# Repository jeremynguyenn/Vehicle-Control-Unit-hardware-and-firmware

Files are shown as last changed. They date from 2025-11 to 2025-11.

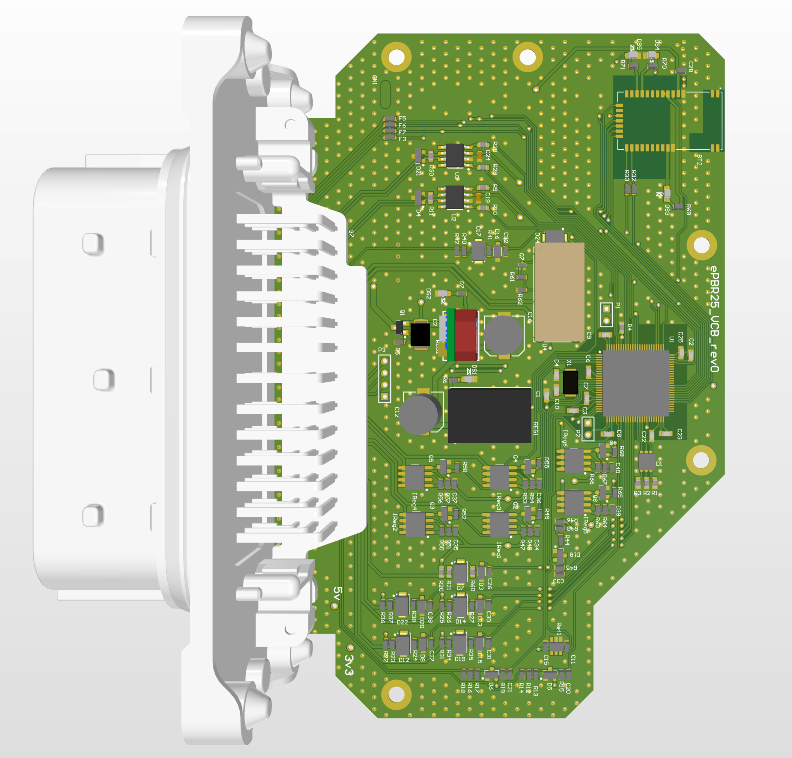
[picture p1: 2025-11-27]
picture/3d_layer_left.png

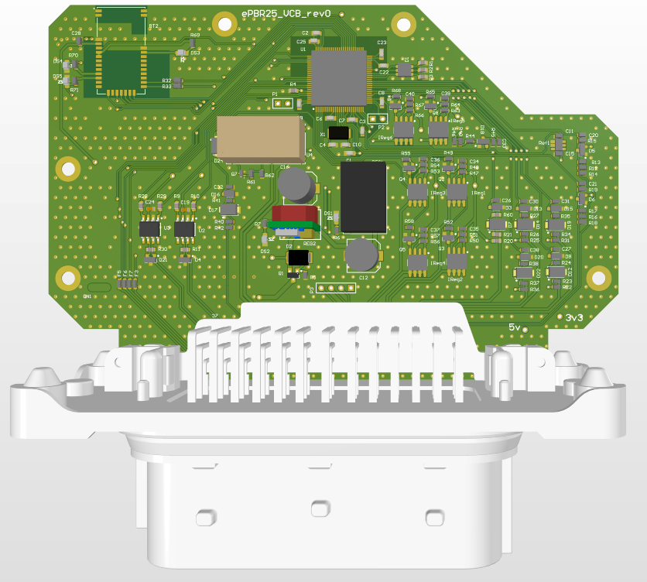
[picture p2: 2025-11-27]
picture/3d_layer.png

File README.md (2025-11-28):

## Picture for the VCU for Electric Vehicle
- 3d View:


- 2d view:


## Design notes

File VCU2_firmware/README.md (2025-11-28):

# Vehicle Control Unit (VCU)

## Introduction
This repository contains the code for the Vehicle Control Unit (VCU) of the Formula Electric SAE Student Team UMSAE Electric. 
The VCU is responsible for the control of the vehicle, including the motor controller, the steering system, and the brake system. 
The VCU is also responsible for the communication with the other ECUs in the vehicle, such as the Accumulator Control Unit (ACU) and the Sensor Control Unit (SCU).

## Building the code
The code is built using STM32CubeIDE.

### Prerequisites
- [STM32CubeIDE](https://www.st.com/en/development-tools/stm32cubeide.html) 
- [STM32CubeMX](https://www.st.com/en/development-tools/stm32cubemx.html)(optional)

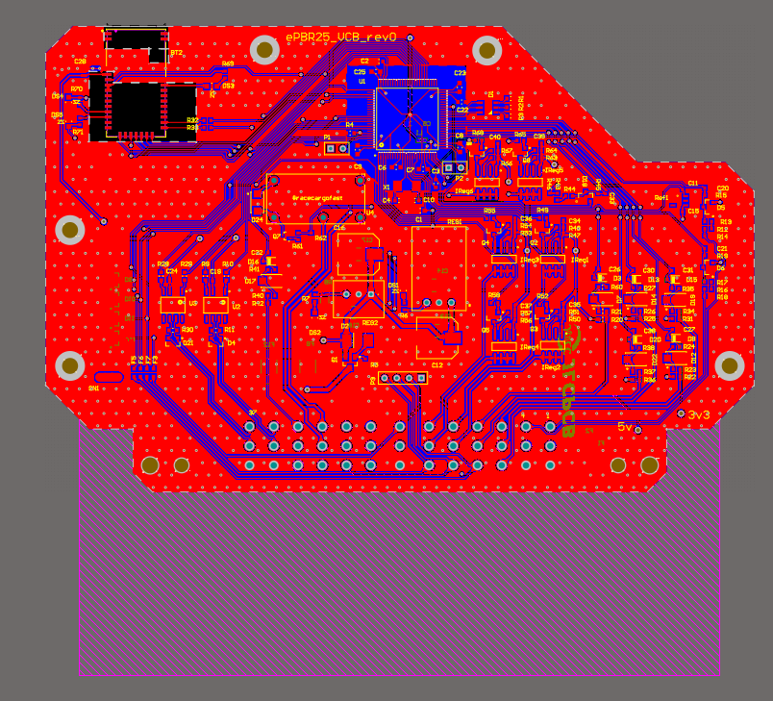
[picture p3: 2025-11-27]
picture/2d_layer.png

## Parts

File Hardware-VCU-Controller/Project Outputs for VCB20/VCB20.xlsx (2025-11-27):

Comment | Description | Designator | Footprint | LibRef | Quantity
WT12 |  | BT1 | WT12 | WT12 | 1
CAP 10nF 100V 0603(1608) | CAP 10nF 100V ±20% 0603 (1608 Metric) Thickness 1mm SMD | C1, C5, C6, C7, C8, C9, C23, C25 | CAPC0603(1608)100_M | CMP-1035-02326-1 | 8
CAP 2.2uF | CAP 2.2uF 10V ±10% 0603 (1608 Metric) Thickness 0.55mm SMD | C2 | CAPC0603(1608)55_N | CMP-1035-02757-1 | 1
CAP 100nF 25V 0603(1608) | CAP 100nF 25V ±20% 0603 (1608 Metric) Thickness 1mm SMD | C3 | CAPC0603(1608)100_N | CMP-1035-02589-1 | 1
CAP 24pF | CAP 24pF 16V ±2% 0603 (1608 Metric) Thickness 1mm SMD | C4, C10 | CAPC0603(1608)100_N | CMP-1035-00843-1 | 2
Cap | Capacitor | C11, C15, C20, C21, C26, C27, C28, C29, C30, C31, C32, C33, C34, C35, C36, C37, C38 | 1608[0603] | Cap | 17
UUD1H101MNL1GS | Aluminum Electrolytic Capacitor, UD Series, Low Impedance, 100 uF, 50 V, + / - 20%, -55 to 105 degC, Chip Type, 8 x 10 mm D x L, Pb-Free, Reel | C12, C16 | NIC-CAPA2-8X10_V | CMP-0687-00073-1 | 2
Cap | Capacitor | C13, C14, C17, C18 | C1210_M | Cap | 4
0.1uF | Chip Capacitor, 100 nF, +/- 10%, 50 V, -55 to 125 degC, 0603 (1608 Metric), RoHS, Tape and Reel | C19, C24 | CAPC1608X90X30NL10T20 | CMP-2000-06092-1 | 2
CAP 2.2uF 10V 0603(1608) | CAP 2.2uF 10V ±10% 0603 (1608 Metric) Thickness 0.55mm SMD | C22 | CAPC0603(1608)55_N | CMP-1035-02757-1 | 1
5-1418363-3 | Levyseal 90 degree 39 pin header | CN1 | 5-1418363-3 | 5-1418363-3 | 1
CLX6F-FKC-CNP1ST1E1BB7D3D3 | Red, Green, Blue (RGB) 622nm Red, 530nm Green, 470nm Blue LED Indication - Discrete 2.1V Red, 2.7V Green, 3V Blue 6-SMD, J-Lead | D1 | CLX6C-FKB | LED - CLX6F-FKC-CNP1ST1E1BB7D3D3 | 1
Zener Diode, 5.1V, 5W SMBJ5338B |  | D2 | DO-214AA (SMB) | Zener Diode, 5.1V, 5W SMBJ5338B | 1
MMSZ5226B-E3-08 | Small Signal Zener Diode, 3.3 V +/- 5%, -55 to 155 degC, 2-Pin SOD-123, RoHS, Tape and Reel | D3, D8, D13, D15, D16, D20 | VISH-SOD-123-2_V | CMP-0931-00026-1 | 6
NUP2105LT1 | Dual Line CAN Bus Protector, 3-Pin SOT-23, Tape and Reel | D4, D21 | ONSC-SOT-23-3-318-08_V | CMP-1063-00165-1 | 2
SZNUP1301ML3T1G | Low Capacitance Diode Array for ESD Protection in a Single Data Line, 3-Pin SOT-23, Pb-Free, Tape and Reel | D5, D6, D9, D10, D11, D18, D23 | ONSC-SOT-23-3-318-08_V | CMP-1063-00171-1 | 7
SS14-E3/5AT | Schottky Barrier Rectifier, 40 V Maximum DC Blocking Voltage, -65 to 125 degC, 2-Pin SMA Case, RoHS | D7, D12, D14, D17, D19, D22, D24 | VISH-DO-214AC-2_V | CMP-0549-00004-1 | 7
LTST-C170GKT | LED Uni-Color Green, 100 mW, 120 mA, -55 to 85 degC, 2-Pin SMD, RoHS, Tape and Reel | DS1, DS2 | LTST-C170GKT_V | CMP-1674-00002-5 | 2
PTC 80 mA | 0ZCM0008FF2G | F1, F2, F3, F5, F6, F7 | 0603 fuse | PTC fuse 80mA 0ZCM0008FF2G | 6
1812L075/24DR | Poly-Fuse(R) Resettable PTC, 24 V, 100 A, -40 to 85 degC, 2-Pin SMD, RoHS, Tape and Reel | F8, F11 | LFUS-1812L07524DR_V | CMP-2000-05510-1 | 2
1812L050/30PR | PTC Resettable Fuse, 0.8 W, 30 V, -40 to 85 degC, 2-Pin SMD, RoHS, Tape and Reel | F9, F10 | LFUS-1812L05030PR_V | CMP-2000-05508-1 | 2
NUD4001 |  | IReg1, IReg2, IReg3, IReg4 | SO8_M | LED Currnet Driver, 500mA, 30V max | 4
MH1608-601Y | Chip Bead, 600 Ohm, 1 A, -55 to 125 degC, 2-Pin SMD (0603), RoHS, Tape and Reel | L1 | BOUR-MH1608_V | CMP-2000-06698-1 | 1
Header 2 | Header, 2-Pin | P1, P2 | HDR1X2 | Header 2 | 2
Header 4 | Header, 4-Pin | P3 | HDR1X4 | Header 4 | 1
FDN340P | Single P-Channel, Logic Level, PowerTrench(R) MOSFET, 2 A, 20 V, -55 to 150 degC, 3-Pin SOT-23, RoHS, Tape and Reel | Q1 | FAIR-SSOT3L-3_V | CMP-2100-03638-1 | 1
MMBT2222ALT1 | General Purpose Transistor, NPN Silicon, 3-Pin SOT-23, Tape and Reel | Q2, Q3, Q4, Q5 | ONSC-SOT-23-3-318-08_V | CMP-1048-00593-1 | 4
IRF7413PBFCT | HEXFET (R) Power MOSFET, 30 V, -55 to 150 degC, 8-Pin SO, RoHS, Tube | Q6 | INTR-SO-8_V | CMP-2000-06466-1 | 1
NTA7002NT1G | Small Signal MOSFET, 30 V, 154 mA, Single, N-Channel, Gate ESD Protection, 3-Pin SC75, Pb-Free, Tape and Reel | Q7 | ONSC-SC-75-3-463-01_V | CMP-1058-00646-1 | 1
82R | 82R 0.1W 5% 0603 (1608 Metric) SMD | R1 | RESC0603(1608)_N | CMP-1012-00048-1 | 1
60R | 60R4 0.1W 1% 0603 (1608 Metric) SMD | R2 | RESC0603(1608)_N | CMP-1012-00372-1 | 1
33R | 33R 0.1W 5% 0603 (1608 Metric) SMD | R3 | RESC0603(1608)_N | CMP-1012-00038-1 | 1
10K | 10K 0.1W 5% 0603 (1608 Metric) SMD | R4 | RESC0603(1608)_N | CMP-1012-00098-1 | 1
Res1 | Resistor | R5, R6, R7, R12, R13, R14, R15, R16, R17, R18, R19, R22, R23, R24, R25, R26, R27, R31, R32, R33, R34, R35, R36, R37, R38, R40, R41, R42, R43, R44, R45, R46, R47, R48, R49, R50, R51, R52, R53, R54, R55, R56, R57, R58, R61, R62 | 1608[0603] | Res1 | 46
100R | 100R 0.25W 5% 1206 (3216 Metric) SMD | R8 | RESC1206(3216)_M | CMP-1014-00050-1 | 1
22R | 22R 0.1W 5% 0603 (1608 Metric) SMD | R9, R10, R28, R29 | RESC0603(1608)_N | CMP-1012-00034-1 | 4
120R | 120R 0.1W 5% 0603 (1608 Metric) SMD | R11, R30 | RESC0603(1608)_N | CMP-1012-00052-1 | 2
100K 5% 0603(1608) | 100K 0.1W 5% 0603 (1608 Metric) SMD | R20 | RESC0603(1608)_N | CMP-1012-00122-1 | 1
51K 5% 0603(1608) | 51K 0.1W 5% 0603 (1608 Metric) SMD | R21, R60 | RESC0603(1608)_N | CMP-1012-00115-1 | 2
100R 1% 0603(1608) | 100R 0.1W 1% 0603 (1608 Metric) SMD | R39 | RESC0603(1608)_N | CMP-1012-00397-1 | 1
10K 1% 0603(1608) | 10K 0.1W 1% 0603 (1608 Metric) SMD | R59 | RESC0603(1608)_N | CMP-1012-00623-1 | 1
LT6654AHS6-3.3 |  | Ref1 | TSOT-23 S6 | LT6654AHS6-3.3 | 1
OKI-78SR-5 |  | REG1 | Reg - TH, 3 pin, 100 mil Pitch, HTL | OKI-78SR-5 | 1
OKI-78SR-3.3 | 3.3V DCDC | REG2 | Reg - TH, 3 pin, 100 mil Pitch, VTL | OKI-78SR-5 | 1
STM32F446VET7 | ARM Cortex-M4 32-bit MCU+FPU, 512 KB Flash, 128 KB Internal RAM, 81 I/Os, 100-Pin LQFP, -40 to 105 degC, Tray | U1 | STM-LQFP100_L | CMP-0243-00221-1 | 1
SN65HVD232DR | 3.3 V Can Transceiver, 17 mA, -40 to 85 degC, 8-pin SOIC (D), Green (RoHS & no Sb/Br) | U2, U3 | D0008A_M | CMP-0315-00075-2 | 2
PE014005 |  | U4 | PE014005 | PE014005 | 1
7A-8.000MAAJ-T |  | X1 | 2-SMD, No Lead | 8MHz crystal, 7A-8.000MAAJ-T | 1

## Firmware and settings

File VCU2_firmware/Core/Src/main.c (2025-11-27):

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
/* Includes ------------------------------------------------------------------*/
#include "main.h"
#include "cmsis_os.h"
#include "adc.h"
#include "can.h"
#include "dma.h"
#include "tim.h"
#include "usart.h"
#include "gpio.h"

/* USER CODE BEGIN Includes */
#include "dashboard_leds.h"
#include "logger.h"
#include "startup_condition.h"
#include "bt_protocol.h"
/* USER CODE END Includes */


void SystemClock_Config(void);
void MX_FREERTOS_Init(void);
/**
  * @brief  The application entry point.
  * @retval int
  */
int main(void)
{

  /* MCU Configuration--------------------------------------------------------*/

  /* Reset of all peripherals, Initializes the Flash interface and the Systick. */
  HAL_Init();

  /* Configure the system clock */
  SystemClock_Config();

  /* Initialize all configured peripherals */
  MX_GPIO_Init();
  MX_DMA_Init();
  MX_CAN1_Init();
  MX_USART2_Init();
  MX_TIM12_Init();
  MX_ADC1_Init();
  /* USER CODE BEGIN 2 */
    dash_set_all_leds();

    if(!logInitialize()){
        //TODO VCU#32 ERROR log initialization failed
        vcu_debug_led(REDLED, true);
    }

    btInitialize();
    checkStartupCondition();

    dash_clear_all_leds();

    vcu_debug_led(GREENLED, true);
    logMessage("INIT: Starting Scheduler\r\n", true);

  /* USER CODE END 2 */

  /* Init scheduler */
  osKernelInitialize();

  /* Call init function for freertos objects (in cmsis_os2.c) */
  MX_FREERTOS_Init();

  /* Start scheduler */
  osKernelStart();

  /* We should never get here as control is now taken by the scheduler */

  /* Infinite loop */
  /* USER CODE BEGIN WHILE */
  while (1)
  {
    /* USER CODE END WHILE */

    /* USER CODE BEGIN 3 */
  }
  /* USER CODE END 3 */
}

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
/**
  * @brief  Period elapsed callback in non blocking mode
  * @note   This function is called  when TIM10 interrupt took place, inside
  * HAL_TIM_IRQHandler(). It makes a direct call to HAL_IncTick() to increment
  * a global variable "uwTick" used as application time base.
  * @param  htim : TIM handle
  * @retval None
  */
void HAL_TIM_PeriodElapsedCallback(TIM_HandleTypeDef *htim)
{
  if (htim->Instance == TIM10) {
    HAL_IncTick();
  }
}

/**
  * @brief  This function is executed in case of error occurrence.
  * @retval None
  */
void Error_Handler(void)
{
  /* USER CODE BEGIN Error_Handler_Debug */
  /* User can add his own implementation to report the HAL error return state */
  //TODO LEDs
  //TODO Error Handling
    //__disable_irq();
    logMessage("ERROR\r\n", true);
    //__enable_irq();
  /* USER CODE END Error_Handler_Debug */
}

#ifdef  USE_FULL_ASSERT
/**
  * @brief  Reports the name of the source file and the source line number
  *         where the assert_param error has occurred.
  * @param  file: pointer to the source file name
  * @param  line: assert_param error line source number
  * @retval None
  */
void assert_failed(uint8_t *file, uint32_t line)
{
  /* USER CODE BEGIN 6 */
  /* User can add his own implementation to report the file name and line number,
     ex: printf("Wrong parameters value: file %s on line %d\r\n", file, line) */
  /* USER CODE END 6 */
}
#endif /* USE_FULL_ASSERT */

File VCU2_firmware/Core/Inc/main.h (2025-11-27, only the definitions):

#define CAN_TX_TASK_ENABLED 1
#define MC_HRTBEAT_TASK_ENABLED 1
#define IWDG_RELOAD_PERIOD 4094
#define BT_DUMP_TASK_ENABLED 0
#define APPS_PROC_TASK_ENABLED 1
#define ACU_HRTBEAT_TASK_ENABLED 1
#define VCU_STATE_TASK_ENABLED 1
#define DASH_LED_TASK_ENABLED 1
#define MC_CAN_COMMS_TASK_ENABLED 1
#define DEFAULT_TASK_ENABLED 0
#define CAN_RX_TASK_ENABLED 1
#define WATCH_DOG_TASK_ENABLED 1
#define ACU_CAN_COMMS_TASK_ENABLED 1
#define IWDG_EVENT_ALL_ALLOWED_BITS 0xFFFFFF
#define RTD_LED2_BLUE_Pin GPIO_PIN_2
#define RTD_LED2_BLUE_GPIO_Port GPIOE
#define TSA_LED2_GREEN_Pin GPIO_PIN_3
#define TSA_LED2_GREEN_GPIO_Port GPIOE
#define RTD_LED1_GREEN_Pin GPIO_PIN_4
#define RTD_LED1_GREEN_GPIO_Port GPIOE
#define TSA_LED1_BLUE_Pin GPIO_PIN_5
#define TSA_LED1_BLUE_GPIO_Port GPIOE
#define APPS1_Pin GPIO_PIN_0
#define APPS1_GPIO_Port GPIOC
#define BPS_Pin GPIO_PIN_2
#define BPS_GPIO_Port GPIOC
#define LC_LED_Pin GPIO_PIN_0
#define LC_LED_GPIO_Port GPIOA
#define TC_LED_Pin GPIO_PIN_1
#define TC_LED_GPIO_Port GPIOA
#define APPS2_Pin GPIO_PIN_5
#define APPS2_GPIO_Port GPIOA
#define VBATT_Pin GPIO_PIN_7
#define VBATT_GPIO_Port GPIOA
#define TRACTION_BTN_Pin GPIO_PIN_5
#define TRACTION_BTN_GPIO_Port GPIOC
#define TSA_BTN_Pin GPIO_PIN_0
#define TSA_BTN_GPIO_Port GPIOB
#define RTD_BTN_Pin GPIO_PIN_1
#define RTD_BTN_GPIO_Port GPIOB
#define LAUNCH_BTN_Pin GPIO_PIN_2
#define LAUNCH_BTN_GPIO_Port GPIOB
#define VCU_LED_BLUE_Pin GPIO_PIN_8
#define VCU_LED_BLUE_GPIO_Port GPIOE
#define VCU_LED_GREEN_Pin GPIO_PIN_9
#define VCU_LED_GREEN_GPIO_Port GPIOE
#define VCU_LED_RED_Pin GPIO_PIN_10
#define VCU_LED_RED_GPIO_Port GPIOE
#define SHUTDOWN_CTL_Pin GPIO_PIN_12
#define SHUTDOWN_CTL_GPIO_Port GPIOE
#define BT_TX_Pin GPIO_PIN_8
#define BT_TX_GPIO_Port GPIOD
#define BT_RX_Pin GPIO_PIN_9
#define BT_RX_GPIO_Port GPIOD
#define BT_RESET_Pin GPIO_PIN_10
#define BT_RESET_GPIO_Port GPIOD
#define BT_NCTS_Pin GPIO_PIN_11
#define BT_NCTS_GPIO_Port GPIOD
#define BT_NRTS_Pin GPIO_PIN_12
#define BT_NRTS_GPIO_Port GPIOD
#define BT_SW_BTN_Pin GPIO_PIN_13
#define BT_SW_BTN_GPIO_Port GPIOD
#define BT_P2_4_Pin GPIO_PIN_14
#define BT_P2_4_GPIO_Port GPIOD
#define BT_P2_0_Pin GPIO_PIN_15
#define BT_P2_0_GPIO_Port GPIOD
#define SHUTDOWN_TAP_Pin GPIO_PIN_6
#define SHUTDOWN_TAP_GPIO_Port GPIOD
#define BT_EAN_Pin GPIO_PIN_7
#define BT_EAN_GPIO_Port GPIOD
#define SENSOR_CAN_RX_Pin GPIO_PIN_5
#define SENSOR_CAN_RX_GPIO_Port GPIOB
#define SENSOR_CAN_TX_Pin GPIO_PIN_6
#define SENSOR_CAN_TX_GPIO_Port GPIOB
#define SAFETY_LOOP_TAP_Pin	SHUTDOWN_TAP_Pin
#define SAFETY_LOOP_TAP_GPIO_Port SHUTDOWN_TAP_GPIO_Port
#define SAFETY_LOOP_CTL_Pin SHUTDOWN_CTL_Pin
#define SAFETY_LOOP_CTL_GPIO_Port SHUTDOWN_CTL_GPIO_Port

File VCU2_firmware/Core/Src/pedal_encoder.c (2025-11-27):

/*
 * pedal_encoder.c
 *
 *
 *This module holds generic functions for processing the pedal encoders.
 */
#include "pedal_encoder.h"
#include <stdlib.h>

#include "logger.h"

#define PEDAL_AGREEMENT_PERCENT 0.10

/*
 * pedalValid
 *
 * PURPOSE: determine if the pedal is in a valid range
 *
 * INPUTS:
 * 		sens_high:	Pedal sensor high gain output
 * 		sens_low:	Pedal sensor low gain output
 * 		state:		APPS pedal state struct
 *
 * 	RETURNS:
 * 		boolean value indicating whether the pedal is in a valid state
 */
bool pedalValid(uint16_t sens_high, uint16_t sens_low, pedal_state_t * state) {
	bool hasPedals = false; 	//true if we etect a pedal
    if((sens_high >= state->high_min && sens_low >= state->low_min)
       && (sens_high <= state->high_max && sens_low <= state->low_max)) { hasPedals = true; }
	return hasPedals;
}

#ifdef OLD_PEDAL_SENSOR
/*
 * This function checks for implausiblity of the apps or brake petal. This function
 * expects the x pattern for the dual sensors where ones output goes up and the
 * others goes down.
 *
 * returns true if the throttle sensors agree otherwise false
 */
bool throttleAgreement_936(uint16_t throttle_1, uint16_t throttle_2,
		pedal_state_t * state) {


	bool agrees = true;
	uint16_t normalized_throttle_2;
	uint16_t throttle_error_max;
	uint16_t throttle_error_min;

	//static uint16_t impos_count = 0;
	//static uint16_t possible_count = 0;

	if (PEDAL_MAX_ENCODER_VAL < throttle_2) {
		normalized_throttle_2 = 0;
	} else {
		normalized_throttle_2 = PEDAL_MAX_ENCODER_VAL - throttle_2;
	}
	if (throttle_1 < TR_MAX_ERROR) {
		throttle_error_min = 0;
	} else {
		throttle_error_min = throttle_1 - TR_MAX_ERROR;
	}

	//no overflows here unless TR_MAX_ERROR >> whole throttle range
	throttle_error_max = throttle_1 + TR_MAX_ERROR;
	//check overflow anyway	//cant overflow on high end because only using 12 bits of 16bit int, watch lowend

	if (throttle_error_max < throttle_1) {
		//throttle overflow
		logMessage("THROTTLE: Overflow", false);
		return false;
	}
	if (state->possibility == PEDAL_POSSIBLE) {
		if (normalized_throttle_2 >= throttle_error_min && normalized_throttle_2 < throttle_error_max) {
			state->impos_count = 0;
		} else {
			state->impos_count++;
		}
		if (state->impos_count < state->impos_limit) {
			agrees = true;
		} else {
			agrees = false;
			//state->impos_count = 0;
			state->possible_count = 0;
			state->possibility = PEDAL_IMPOSSIBLE;
			//handleImpossiblilty();
			logMessage("THROTTLE: Throttle Disagreement", false);
		}
	} else {
		agrees = false;
		/*
		//try to recover from impossible state, ambiguous in rules
		if (normalized_throttle_2 >= throttle_error_min && normalized_throttle_2 < throttle_error_max) {
			state->possible_count++;
		} else {
			state->possible_count = 0;
		}
		if (state->possible_count < state->impos_limit) {
			agrees = false;
		} else {
			agrees = true;
			state->impos_count = 0;
			state->possible_count = 0;

			state->possibility = PEDAL_POSSIBLE;
			logMessage("THROTTLE: Throttle Sensors have reached an agreement", false);
		}
		*/
	}
	return agrees;
}
#endif



/*
 * This function checks for implausibility of the apps and brake pedal.
 * This function expects two offset slopes for sensor ranges. It checks that these two slopes agree within 10%.
 * Rule T.4.2.4 in 2024 FSAE Rules v1
 *
 * Note these ranges are scaled by a factor of 3.3/5
 *
 * sens_high: 	high gain petal sensor ADC reading
 * sens_low: 	low gain petal sensor ADC reading
 *
 * RETURN true if the throttle sensors agree within 10% otherwise false
 */
bool rule_10percent_pedal_travel_apps_agreement(uint16_t sens_high, uint16_t sens_low, pedal_state_t * state)
{
    // Calculate the expected sens_high value from sens_low
    double expected_sens_high = (1.8759f * (float)sens_low) - 192.03f;

    // Calculate the 10% range for the expected sens_high value
    double agreement_range_min = expected_sens_high * (1.0f - PEDAL_AGREEMENT_PERCENT);
    double agreement_range_max = expected_sens_high * (1.0f + PEDAL_AGREEMENT_PERCENT);

    // Check if the actual sens_high value falls within this range
    bool within_range = (sens_high >= agreement_range_min) && (sens_high <= agreement_range_max);

    if (state->possibility == PEDAL_POSSIBLE)
    {
        state->impos_count = within_range ? 0 : state->impos_count + 1;
        if(state->impos_count >= state->impos_limit){
            state->possibility = PEDAL_IMPOSSIBLE;
            logMessage("APPS: Sensor Disagreement", false);
        }
        else {
            within_range = true;
        }
    }
    else
    {
        state->possible_count = within_range ? state->possible_count + 1 : 0;
        if (state->possible_count >= state->impos_limit) {
            state->impos_count = 0;
            state->possible_count = 0;
            state->possibility = PEDAL_POSSIBLE;
            logMessage("APPS: Sensors have reached an agreement", false);
        }
        else {
            within_range = false;
        }
    }

    return within_range;
}

/*
 * Error handler for bad pedal struct
 */
void bad_pedal_struct_err_handler() {
	//do nothing :(
    //TODO VCU#32 ERROR Bad pedal struct thing
}

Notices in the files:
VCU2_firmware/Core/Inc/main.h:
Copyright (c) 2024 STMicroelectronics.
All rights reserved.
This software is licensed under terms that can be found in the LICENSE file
